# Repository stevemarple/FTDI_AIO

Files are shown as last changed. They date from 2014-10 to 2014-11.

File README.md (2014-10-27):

# FTDI all-in-one

The FTDI all-in-one is a USB-UART converter, a bit-banging AVR ISP 
programmer, a breakout board and USB switch and LED.

## License

Unless indicated otherwise hardware is released under the Creative
Commons Attribution-ShareAlike 3.0 Unported (CC BY-SA 3.0)
http://creativecommons.org/licenses/by-sa/3.0/

Unless indicated otherwise software is released under the GNU Lesser
General Public License, version 2.1.
http://www.gnu.org/licenses/lgpl-2.1.html

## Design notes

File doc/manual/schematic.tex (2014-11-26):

\begin{landscape}
  \begin{figure}[p]
    \section{Schematic}
    \centering
    \includegraphics[keepaspectratio,width=28cm,height=16cm]{%
      images/FTDI_AIO_sch}
     \caption{FTDI all-in-one v.~1.0 circuit diagram.}
  \end{figure}
\end{landscape}

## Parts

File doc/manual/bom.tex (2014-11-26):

\newlength{\widthManufacturer}
\settowidth{\widthManufacturer}{Manufacturer}
\begin{landscape}
  \section{Bill of materials}
  \tablefirsthead{%
    \hline
    Part & 
    Description & 
    Manufacturer & 
    Manufacturer part number & 
    Supplier &
    Order code \\
    \hline \hline %% ------
  }
  \tablehead{%
    \multicolumn{6}{l}{\small \textsl{continued from previous page}} \\
    \hline
    Part & 
    Description & 
    Manufacturer & 
    Manufacturer part number & 
    Supplier &
    Order code \\
    \hline \hline
  }
  \tabletail{%
    \hline
    \multicolumn{6}{r}{\small \textsl{continued on next page}} \\
    }
  \tablelasttail{%
    \hline
    }

  \begin{supertabular}{|p{2cm}|>{\raggedright}p{8cm}%
      |>{\raggedright}p{\widthManufacturer}%
      |p{5cm}|p{\widthManufacturer}|p{\widthManufacturer}|}
    C1 & \uF{1} 1206 \smt\ capacitor & & & Farnell & \\ 
    C2 & \uF{1} 1206 \smt\ capacitor & & & Farnell & \\ 
    C3 & \nF{100} 1206 \smt\ capacitor & & & Farnell & \\ 
    C4 & \nF{10} 1206 \smt\ capacitor & & & Farnell & \\ 
    C5 & \uF{4.7} 1206 \smt\ capacitor & & & Farnell & \\ 
    C6 & \nF{100} 1206 \smt\ capacitor & & & Farnell & \\ 
    C7 & \nF{100} 1206 \smt\ capacitor & & & Farnell & \\ 
    IC1 & \volt{3.3} regulator & Microchip & MCP1702-3302E/TO & Farnell & \\ 

    IC2 & USB-UART converter & FTDI & FT232RL 
    & {CPC \newline Farnell}
    & {SC10141 \newline 1146032} \\

    JP1 & $2 \times 3$ jumper block & & & & \\
    L1 & 0805 \smt\ ferrite bead & Laird technologies & MI0805K400R-10
    & Farnell & 2292459 \\
    LED1 & Diffuse yellow \led & Kingbright & L-7104YD & CPC & SC08015 \\
    LED2 & Diffuse red \led & Kingbright & L-7104ID & CPC & SC08013 \\
    LED3 & Diffuse green \led & Kingbright & L-7104GD & CPC & SC08014 \\
    R1 & 1206 \smt\ resistor & & & Farnell & \\
    R2 & 1206 \smt\ resistor & & & Farnell & \\
    R3 & \ohm{0} 1206 \smt\ resistor%
    \footnote{Fit only if not using IC1} & & & Farnell & \\
    R4 & \kohm{1} 1206 \smt\ resistor & & & Farnell & \\
    R5 & \kohm{1} 1206 \smt\ resistor & & & Farnell & \\
    R6 & \kohm{1} 1206 \smt\ resistor & & & Farnell & \\
    R7 & 1206 \ohm{560} \smt\ resistor & & & Farnell & \\
    R8 & 1206 \ohm{560} \smt\ resistor & & & Farnell & \\
    R9 & \kohm{1} 1206 \smt\ resistor & & & Farnell & \\
    S1 & Switch & & & Farnell & \\
    X1 & & & & Farnell & \\
    X2 & & & & Farnell & \\
    X3 & & & & Farnell & \\
    Shunt 1 & Fit to JP1 & & & & \\
    Shunt 2 & Fit to JP1 & & & & \\
    PCB & Circuit board  & & & & \\
  \end{supertabular}  
\end{landscape}

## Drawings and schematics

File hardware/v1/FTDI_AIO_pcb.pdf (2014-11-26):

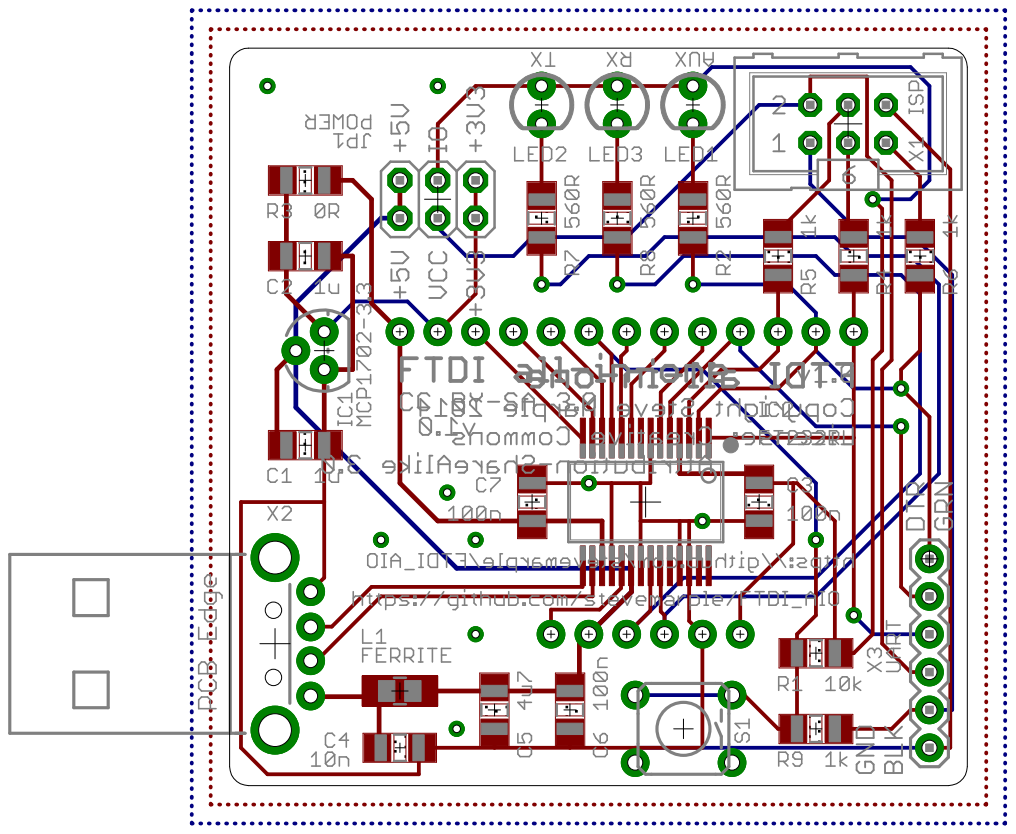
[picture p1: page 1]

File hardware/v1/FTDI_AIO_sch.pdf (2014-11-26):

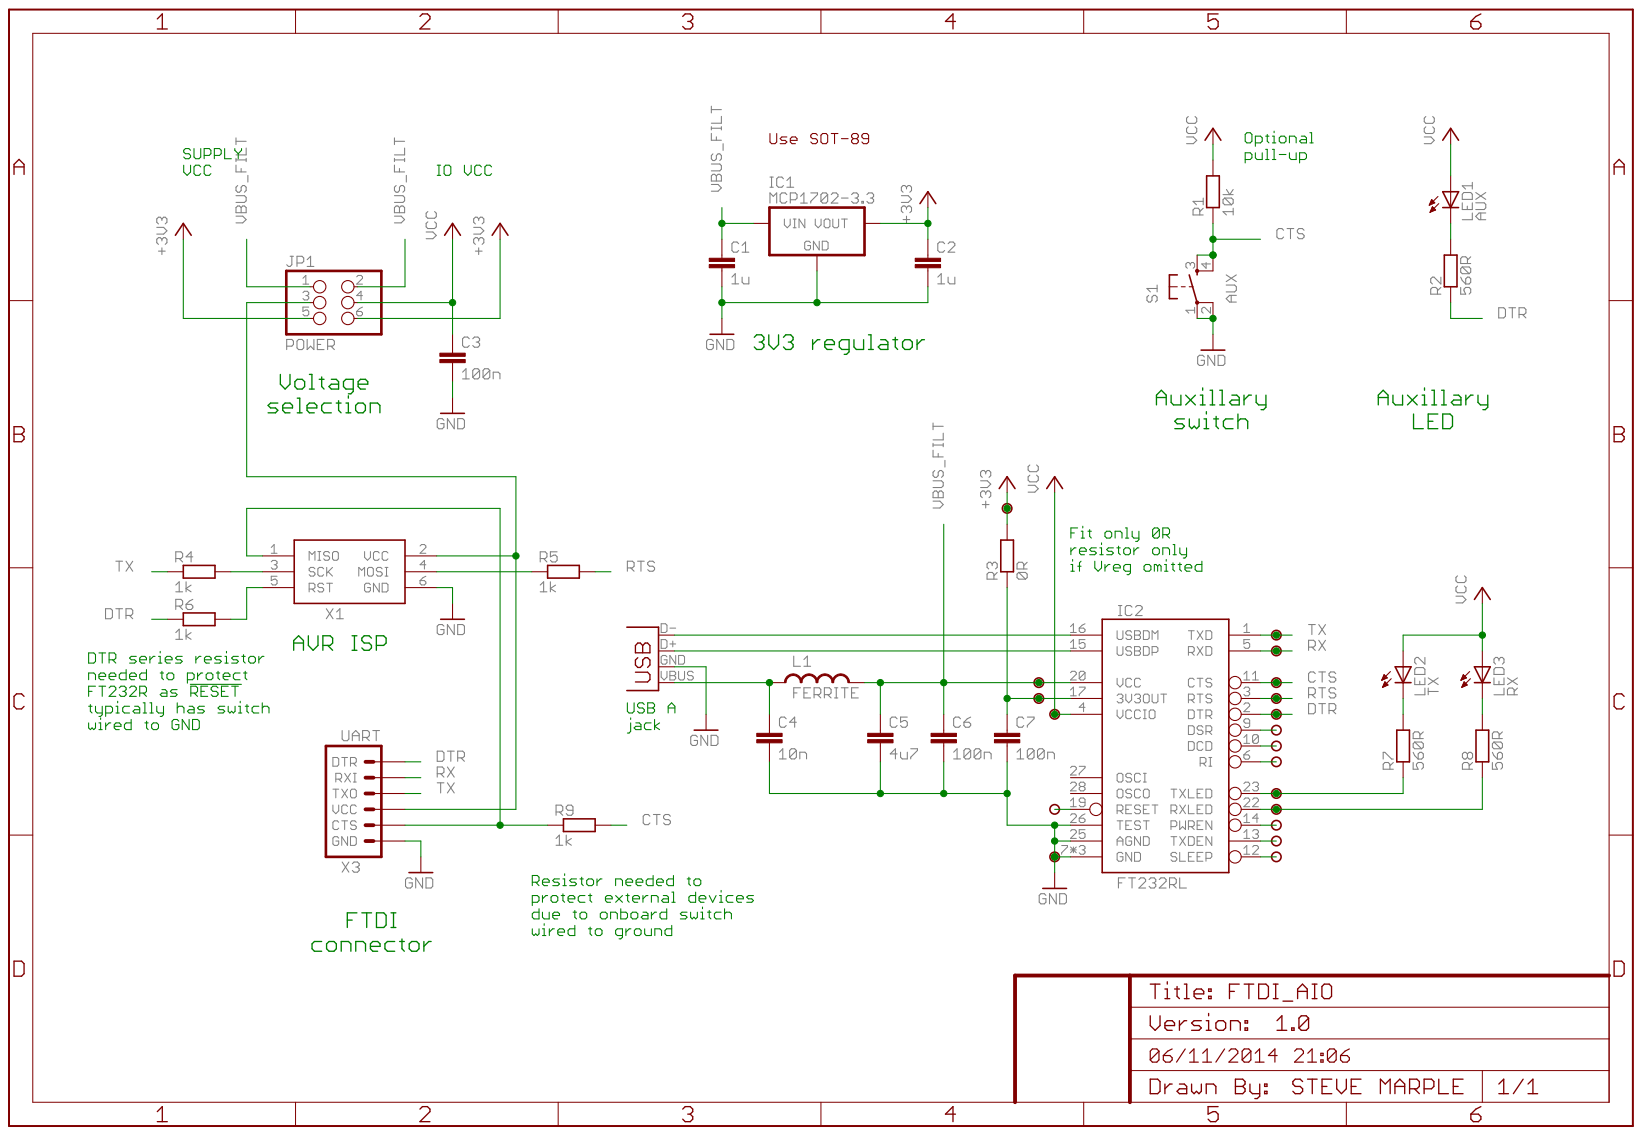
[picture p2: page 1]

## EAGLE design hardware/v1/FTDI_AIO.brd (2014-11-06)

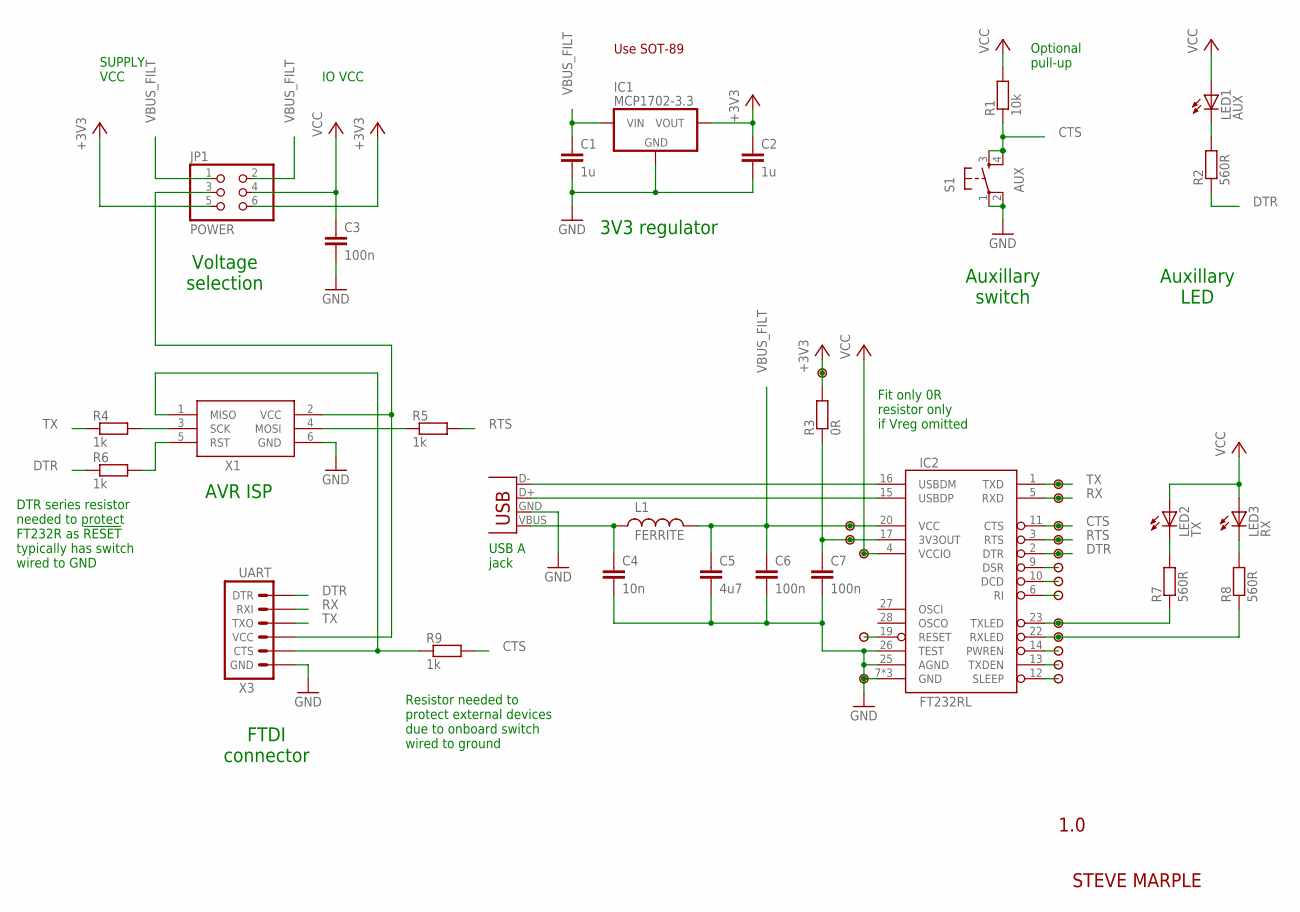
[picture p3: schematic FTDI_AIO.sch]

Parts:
C1, C2: 1u; 1206-HAND
C3, C6, C7: 100n; 1206-HAND
C4: 10n; 1206-HAND
C5: 4u7; 1206-HAND
IC1: MCP1702-3.3; TO-92
IC2: FT232RL; SSOP28-HAND
JP1: POWER; 2X03
L1: FERRITE; 0805-HAND
LED1: AUX; LED3MM
LED2: TX; LED3MM
LED3: RX; LED3MM
R1: 10k; 1206-HAND
R2, R7, R8: 560R; 1206-HAND
R3: 0R; 1206-HAND
R4, R5, R6, R9: 1k; 1206-HAND
S1: AUX; TACTILE-PTH
U$1, U$2, U$3, U$4, U$5, U$6, U$7, U$8, U$9, U$10, U$11, U$12, U$13, U$14, U$15, U$16, U$17, U$18, U$19: PAD
X1: ISP; CONN-HARTING-ML6
X2: USB-A-H
X3: UART; 1X06

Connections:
3V3_OUT: C7.1, IC2.17 (3V3OUT), R3.1, U$6.1
!RESET: IC2.19 (RESET), U$14.1
+3V3: C2.1, IC1.3 (VOUT), JP1.5, JP1.6, R3.2, U$1.1
CTS: IC2.11 (CTS), R1.1, R9.2, S1.3, S1.4, U$5.1
CTS_PROT: R9.1, X1.1 (MISO), X3.5 (CTS)
DTR: IC2.2 (DTR), R2.1, R6.1, U$9.1, X3.1 (DTR)
EXT_VCC: JP1.3, X1.2 (VCC), X3.4 (VCC)
GND: C1.2, C2.2, C3.2, C4.2, C5.2, C6.2, C7.2, IC1.1 (GND), IC2.7 (GND), IC2.18 (GND), IC2.21 (GND), IC2.25 (AGND), IC2.26 (TEST), S1.1, S1.2, U$18.1, X1.6 (GND), X2.GND (VBUS), X3.6 (GND)
unnamed: LED1.K (C), R2.2
unnamed: R5.1, X1.4 (MOSI)
unnamed: LED2.K (C), R7.2
unnamed: LED3.K (C), R8.2
unnamed: IC2.9 (DSR), U$10.1
unnamed: IC2.10 (DCD), U$11.1
unnamed: IC2.6 (RI), U$12.1
unnamed: IC2.14 (PWREN), U$16.1
unnamed: IC2.13 (TXDEN), U$17.1
unnamed: IC2.12 (SLEEP), U$19.1
RST: R6.2, X1.5 (RST)
RTS: IC2.3 (RTS), R5.2, U$7.1
RX: IC2.5 (RXD), U$3.1, X3.2 (RXI)
RXLED: IC2.22 (RXLED), R8.1, U$15.1
SCK: R4.2, X1.3 (SCK)
TX: IC2.1 (TXD), R4.1, U$2.1, X3.3 (TXO)
TXLED: IC2.23 (TXLED), R7.1, U$13.1
USB_D+: IC2.15 (USBDP), X2.D+ (D-)
USB_D-: IC2.16 (USBDM), X2.D- (D+)
VBUS_FILT: C1.1, C5.1, C6.1, IC1.2 (VIN), IC2.20 (VCC), JP1.1, JP1.2, L1.2, U$4.1
VCC: C3.1, IC2.4 (VCCIO), JP1.4, LED1.A, LED2.A, LED3.A, R1.2, U$8.1
VUSB: C4.1, L1.1, X2.VBUS (GND)

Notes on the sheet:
FTDI connector
Optional pull-up
IO VCC
SUPPLY VCC
AVR ISP
Voltage selection
Auxillary switch
Auxillary LED
1.0
STEVE MARPLE
USB A jack
3V3 regulator
Use SOT-89
Fit only 0R resistor only if Vreg omitted
Resistor needed to protect external devices due to onboard switch wired to ground
DTR series resistor needed to protect FT232R as !RESET! typically has switch wired to GND

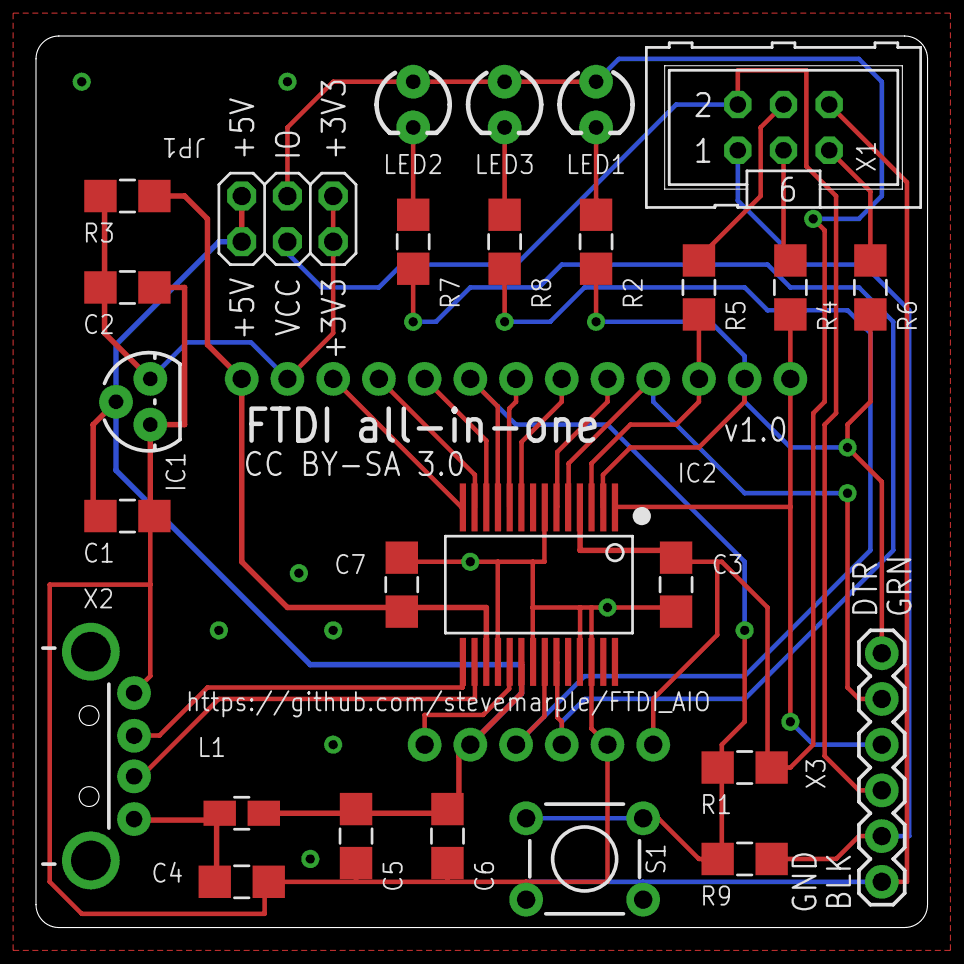
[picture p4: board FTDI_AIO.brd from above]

Board: 2 copper layers, 49.5 x 49.5 mm, 46 parts (0 on the bottom side), 30 nets.

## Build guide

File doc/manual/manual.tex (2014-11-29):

\documentclass[twoside,a4paper,openany,12pt]{article}

%%\documentclass[twoside,a4paper,12pt]{article}
%\documentclass[twoside,a4paper,openany,12pt]{report}

%% Document has convention that only first letter of chapters,
%% sections is capitalized. Do the same for automatic sections
\renewcommand\listfigurename{List of figures}
\renewcommand\listtablename{List of tables}
\newcommand{\secname}{Section}

%% Convenient way to specify margins
\usepackage[a4paper,top=2.5cm,bottom=2.5cm,inner=2.5cm,outer=2.5cm]{geometry}

%% Relative font sizes
\usepackage{relsize}

%% Use font with 8-bit encoding
\usepackage[T1]{fontenc}

%% Nicer fonts
\usepackage{pslatex}

\usepackage{linegoal}

\usepackage{array}
%\usepackage{longtable}
\usepackage{supertabular}
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
  \ifthenelse{\equal{#4}{}}{}{ \href{#4}{#4}}}

%% Environment variables. Like \filename but prepends a $
\DeclareUrlCommand\envVar{\def\UrlLeft{\$}\urlstyle{tt}}
\DeclareUrlCommand\dosEnvVar{\def\UrlLeft{\%}\def\UrlRight{\%}\urlstyle{tt}}

\newcommand{\code}[1]{\texttt{#1}}
\newcommand{\username}[1]{\texttt{#1}}
\newcommand{\piUser}{\username{pi}}
\newcommand{\rootUser}{\username{root}}

%% Use for menu selections etc
\newcommand{\myquote}[1]{\textcolor{MyQuoteColor}{\textsl{#1}}}

%% Define our own keypress command, based on keystroke
\newcommand{\keypress}[1]{\keystroke{#1}}

%% Units
%%\newcommand{\units}[2]{\mbox{\ensuremath{#1}\,#2}}
%%\newcommand{\dB}[1]{\mbox{\ensuremath{#1}\,dB}}
\newcommand{\dB}[1]{\SI{#1}{dB}}
%%\newcommand{\inch}[1]{\mbox{\ensuremath{#1}''}}
\newcommand{\inch}[1]{\SI{#1}{''}}
\newcommand{\Hz}[1]{\SI{#1}{\hertz}}
\newcommand{\kHz}[1]{\SI{#1}{\kilo\hertz}}
\newcommand{\MHz}[1]{\SI{#1}{\mega\hertz}}
\newcommand{\volt}[1]{\SI{#1}{V}}
  \newcommand{\voltOLD}[1]{\mbox{\ensuremath{#1}\,V}}
\newcommand{\bit}[1]{\mbox{\ensuremath{#1}\,bit}}

%%\newcommand{\degrees}[1]{\ensuremath{#1^\circ}}

\renewcommand{\textohm}{\ensuremath{\Omega}}
\newcommand{\ohm}[1]{\SI{#1}{\ohm}}
\newcommand{\kohm}[1]{\SI{#1}{\kilo\ohm}}

\newcommand{\pF}[1]{\SI{#1}{\pico\farad}}
\newcommand{\nF}[1]{\SI{#1}{\nano\farad}}
\newcommand{\uF}[1]{\SI{#1}{\micro\farad}}

\newcommand{\uH}[1]{\SI{#1}{\micro\henry}}

\newcommand{\nT}[1]{\SI{#1}{\nano\tesla}}

\newcommand{\MB}[1]{\SI{#1}{\mega\byte}}
%% Some simple abbreviations  
\newcommand{\ie}{i.e.}
\newcommand{\eg}{e.g.}
\newcommand{\etal}{\latin{et al.}}
\newcommand{\etc}{etc.}

%% Have warnings printed in light red box, with each item using a
%% STOP sign as a bullet
\newenvironment{warninglist}{%
  \begin{list}{\Stopsign}{}}{%
    \end{list}}
\newcommand{\warningbox}[1]{\noindent%
  \colorbox{MyLightRed}{\parbox{\textwidth}{%
      \begin{warninglist}\item #1\end{warninglist}}} \newline}

%% Have help information printed in light blue box, with each item using an
%% information sign as a bullet
\newenvironment{helplist}{%
  \begin{list}{\Info}{}}{%
    \end{list}}
\newcommand{\helpbox}[1]{\noindent
  \colorbox{MyLightBlue}{\parbox[l]{\textwidth}{%
      \begin{helplist}\item #1\end{helplist}}} \newline}
\newcommand{\examplebox}[2][]{\noindent
  \colorbox{MyYellow}{\parbox[l]{\textwidth}{\ifthenelse{\equal{#1}{}}%
      {Example: }{#1}\vspace*{1ex} \newline %
      #2 %
      \vspace*{1ex}}} \newline}

%% Verbatim-like environment for code.
\DefineVerbatimEnvironment{Code}{Verbatim}%
{frame=single,commandchars=\\\{\}}
\DefineVerbatimEnvironment{Cmd}{Verbatim}%
{frame=single,framesep=5mm,commandchars=\\\{\}}
% {frame=single,label=\linuxLogo,framesep=5mm,commandchars=\\\{\}}
\DefineVerbatimEnvironment{LinuxCmd}{Verbatim}%
{frame=single,framesep=5mm,commandchars=\\\{\}}
% {frame=single,label=\linuxLogo,framesep=5mm,commandchars=\\\{\}}
\DefineVerbatimEnvironment{WindowsCmd}{Verbatim}%
{frame=single,framesep=5mm,commandchars=\\\{\}}
% {frame=single,label=\windowsLogo,framesep=5mm,commandchars=\\\{\}}

%% \DefineVerbatimEnvironment{Cmd}{LinuxCmd}{}

\DefineVerbatimEnvironment{RootCmd}{Verbatim}%
{frame=single,framesep=5mm,label=As user \rootUser,commandchars=\\\{\}}
\DefineVerbatimEnvironment{PiCmd}{Verbatim}%
{frame=single,framesep=5mm,label=As user \piUser,commandchars=\\\{\}}

\newcommand{\todo}[1][]{\fcolorbox{magenta}{MyLightMagenta}{\mbox{\textcolor{black}{TO DO\ifthenelse{\equal{#1}{}}{}{: #1}}}}}

\newcommand{\figscale}{1.0}

%% Have subsubsections numbered
\setcounter{secnumdepth}{5}
\setcounter{tocdepth}{5}

\newenvironment{buildorder}{%
  \begin{enumerate}%
    \setlength{\itemsep}{0pt}%
    \setlength{\parskip}{0pt}}%
  {\end{enumerate}}

\newcommand{\copyrightyear}{%
  \ifthenelse{\equal{\gitCommitYear}{2014}}{2014}{2014--\gitCommitYear}}
\newcommand{\documentAttribution}{``FTDI all-in-one manual. Steve
  R. Marple. \gitCommitYear. \githubRepoUrl''}

\begin{document}

\title{FTDI all-in-one manual\\ \vspace*{1ex}
  \smaller \href{\githubRepoUrl}{\githubRepoUrl}}
\author{Steve R. Marple}
\date{\gitCommitDate\\
  \small{Commit: \gitCommit}}
\maketitle
\thispagestyle{empty}
\pagestyle{plain}

% \clearpage  
\phantomsection  
\addcontentsline{toc}{section}{Licence}  
% % \thispagestyle{empty}
\section*{Licence}
\href{\githubRepoUrl}{FTDI all-in-one} manual by Steve R. Marple is
licensed under a \href{\ccBySaFourUrl}{Creative Commons Attribution
  ShareAlike 4.0 International License}.

\begin{center}
\href{\ccBySaFourUrl}{}
\end{center}

Please attribute this work as\\*
\documentAttribution

%% Allow for sloppy wordbreaking to avoid text spilling into the
%% margin (eg as a result of \filename and other non-breaking text)
\sloppy

\input{construction}
\clearpage
\input{operation}

\appendix
\renewcommand{\thesection}{Appendix~\Alph{section}}

% Use include here, more efficient and want on new pages
\include{bom}
\include{schematic}
\end{document}

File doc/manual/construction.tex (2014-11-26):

\section{Construction}

Begin construction with IC2, the FT232RL, as this component is the
most difficult and access is easiest with an empty \pcb. Then fit L1,
R1, R2 and R4--R8. Note that R3 should be omitted if you plan to fit
the external \volt{3.3} regulator (IC1). Then fit C3--C7. If using the
external regulator fit C1, C2. Fit the UART connector (X3) and the USB
connector (X2). Then fit the \led{}s, yellow for LED1 (AUX), red for
LED2 (TX) and green for LED3 (RX). Fit X1, the box connector for the
ISP interface; ensure the slotted part is away from the edge of the
\pcb. If using the external regulator fit IC1. Finally add shunts to
JP1 to select the I/O and VCC voltages.

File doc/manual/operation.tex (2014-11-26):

\section{Operation}

\subsection{Selection of logic levels}

\subsection{Selection of operating voltage for connected device}

\warningbox{Standard Arduino boards which operate at \volt{3.3}
  commonly have the Vcc pin on the ISP interface wired to \volt{5}.
  This is contrary to normal Atmel protocol where the Vcc pin is used
  to select the logic level voltage. If in any doubt over the correct
  setting for Vcc remove the Vcc shunt from JP1.}

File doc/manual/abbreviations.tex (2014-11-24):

%% List of abbreviations. Include all useful ones. Those which are not
%% used are not included in the table.

\abbrev{\dtr}{DTR}{data terminal ready}
\abbrev{\eeprom}{EEPROM}{electrically erasable programmable read-only memory}
\abbrev{\esd}{ESD}{electro-static discharge}
\abbrev{\fet}{FET}{field-effect transistor}
\abbrev{\ic}{IC}{integrated circuit}
\abbrev{\itwoc}{I2C}{inter-integrated circuit (bus)}
\abbrev{\isp}{ISP}{in-circuit serial programmer (sometimes abbreviated as ICSP)}
\abbrev{\led}{LED}{light emitting diode}
\abbrev{\pcb}{PCB}{printed circuit board}
\abbrev{\psu}{PSU}{power supply unit}
\abbrev{\sd}{SD}{secure digital}
\abbrev{\smt}{SMT}{surface-mount technology}
\abbrev{\soic}{SOIC}{small outline integrated circuit}
\abbrev{\ttl}{TTL}{transistor-transistor logic}
%% \url is already a command, use \URL for the abbreviation
\abbrev{\URL}{URL}{uniform resource locator}
\abbrev{\usb}{USB}{universal serial bus}

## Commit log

2014-10-27 Adding README and hardware design files.
    [FTDI_AIO.brd, FTDI_AIO.sch]
2014-10-27 Moved jumper block. Updated FT232RL package.
    Jumper block moved to make room for larger text describing jumper options.
    Updated FT232RL so that silkscreen does not printer over pads.
    [FTDI_AIO.brd, FTDI_AIO.sch]
2014-10-27 Increasing power line track width to 0.012".
    [FTDI_AIO.brd, FTDI_AIO.sch]
2014-10-28 Rounding corners and adding vias between ground planes.
    [FTDI_AIO.brd]
2014-10-28 Minor track and via changes.
    [FTDI_AIO.brd]
2014-10-30 Adding CAM file for Gerber file creation.
2014-10-30 Adding design rules files for 10 mil track and spacing.
2014-11-04 Updating to use modified FT232R package. Rerouted TXLED.
    TXLED signal rerouted to avoid breaking ground place in vicinity of
    USB data lines.
    [FTDI_AIO.brd, FTDI_AIO.sch]
2014-11-04 Swapping capcitor positions for better decoupling.
    [FTDI_AIO.brd]
2014-11-04 Adding decoupling capacitor for FT232R VCCIO.
    [FTDI_AIO.brd, FTDI_AIO.sch]
2014-11-04 Adding Gerber files.
    [FTDI_AIO.GBL, FTDI_AIO.GBO, FTDI_AIO.GBS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]
2014-11-06 Ensuring all silkscreen is within board outline.
    [FTDI_AIO.brd, FTDI_AIO.sch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]
2014-11-26 Adding schematic and other documentation.
2014-11-26 Adding schematic and PCB layout.

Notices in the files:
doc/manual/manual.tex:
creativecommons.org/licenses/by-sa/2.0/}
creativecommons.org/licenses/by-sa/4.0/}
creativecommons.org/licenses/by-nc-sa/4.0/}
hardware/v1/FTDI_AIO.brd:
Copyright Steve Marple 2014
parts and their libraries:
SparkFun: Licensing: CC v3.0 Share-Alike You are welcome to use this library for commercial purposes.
